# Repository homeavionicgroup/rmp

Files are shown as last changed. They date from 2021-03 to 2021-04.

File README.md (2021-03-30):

# Radio Management Panel for your HomeCockpit
Radio Management Panel for HomeCockpit Use

This Repository shows the requred sources to build a Radio Management Panel for the use with your Home Flightsimulator. Currently it only works with X-Plane (FF320, ToLiss321, FF350) and the MSFS server is currently worked on. 

 # For Flight Simulation use only. No warranties, use at your own risk

Currently the RMP allows following functions:
1. VHF Management 
2. SQWk Management 
3. SIMBrief Integration 
with more to follow.

You need the following: 
1. 3D Model
2. Electronic
3. Some Code

For the full List of parts you need please view the Ingredientslist:
https://github.com/homeavionicgroup/rmp/blob/main/documentation/Ingredients.md

### Screenshots
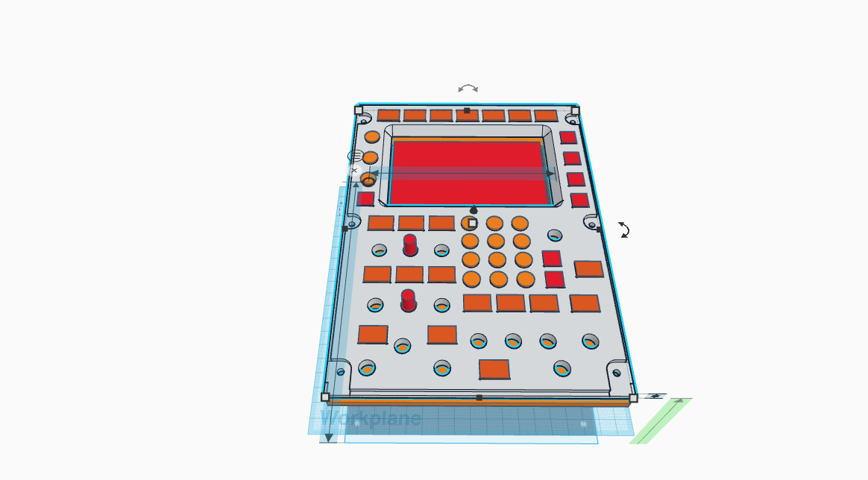
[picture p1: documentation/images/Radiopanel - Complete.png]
ScreenShot Complete


## Wiring
Howto wire all the elements is described in the corresponding documentation: 

# LICENSE
This project and all it's elements are shared under the Creative Commons Attribution-NonCommercial-ShareAlike 4.0 International Public License:
https://creativecommons.org/licenses/by-nc-sa/4.0/

# DISCLAIMER 
 *+For Flight Simulation use only. No warranties, use at your own risk. **

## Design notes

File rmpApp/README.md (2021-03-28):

# Client App

This directory contains the main application and configurations, which runs on the Radio Management Panel. The application is a basic html-app, which can be hosted directly on the PI itself or on an external Webbrowser. 

The client app is configured through the config.js file, which can be found in the /rmpApp/common/js/config.js file. There you store the servers IP-Address + Port and your SimBrief Username, if you want to use the Simbrief feature. The application starts with a simple menu (index_radio.html), which allows you to start the radio configurations for specific planes. Currently only the FF320 is supported with others to come.

# rpi config
The buttons (see wiring) of the Raspberry are directly used as keyboard keys through the dtoverlay option on the raspberry. Put the lines in that configurationsfile in config.txt within the boot directory to load it on boot. 

# Pico Config
As dresribed earlier the raspberry pico is used as GPIO extension and acts as a keyboard connected through USB to the raspberry pi. For this to work load the current circuitpython firmware on your pico and put the code from the Radio-pico.py to the code.py on the pico.

# Key Assignments
Following Key assigments do currently work with the pico:

- LSKL1	    a
- LSKL2	    s
- LSKL3	    d
- LSKL4	    f
- LSKR1	    g
- LSKR2	    h
- LSKR3	    j
- LSKR4	    k
- Menu 1	q
- Menu 2	w
- Menu 3	e
- Menu 4	r
- Menu 5	t
- Menu 6	z
- Menu 7	u
- COM1	    i
- COM2	    o
- COM3	    p
- UP  BTN	UP
- Down BTN	DOWN
- 1 BTN	    1
- 2 BTN	    2
- 3 BTN	    3
- 4 BTN	    4
- 5 BTN	    5
- 6 BTN	    6
- 7 BTN	    7
- 8 BTN	    8
- 9 BTN	    9
- 0 BTN	    0
- . BTN	    .
- CLR BTN	c

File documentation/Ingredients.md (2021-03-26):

# Ingredients 

## 3D Model
The components for the 3D Modell are available as STL to be printed by the 3DPrinter of your choice. The Frontplate is hosted externally but the other (fitting) elements are in the corresponding folder in this repository. 

### Front Plate
As Front Plate I found following available Model on thingyverse: https://www.thingiverse.com/thing:2892991 and adapted it to fit it better with the buttons and the backplate. Checkout russ1364 model portfolio on thingyverse. He has some amazing stuff available if you look for Airbus specific material. 

### Back Plate
To fit the electronics (Buttons, Display etc.)I created a Backplate with holds that stuff and is mouted directly beneath the FrontPlate

### Buttons
You need Buttons in following numbers:
- 21 x Radiopanel-Button-big
- 3 x Radiopanel-Button-round (Big Dot)
- 3 x Radiopanel-Button-small (BAR)
- 2 x Radiopanel-Button-small (up)
- 1 each of (Radiopanel-Button-round (0-9),Radiopanel-Button-round (CLR), Radiopanel-Button-round (Dot), Radiopanel-Button-small (MSGCLR), Radiopanel-Button-small (RST)9

## Electronics

### Elements
You need following eletronics:
- 1 x Raspberry Pi 3 A+ 
- 1 x Waveshare 4.3 inch Touch Display with DSI Interface
- 1 x Raspberry Pico
- 43 x Omron B3F-4030
- 2 x KY-040 Rotary Encoders
- Lots of kables & Soldering equipment
- 1x short Micro USB cable to connect the Pico (20mm)
- 1x Micro USB cable with sufficient length (depending on where your USB Power Source is)
- Some blank PCBs to combine the ground cables (can be solved otherwise)

## Other
To hold everything together I use M4 screws with minimum of 30mm length incl. lots of washers and nuts. As to keep the elecontrics (especially the buttons and rotaries) in place, I use double-sided adhesive pads. For a less chaos I additionally use cable labeles, which makes the wiring a lot easier.

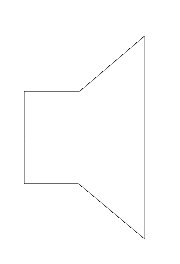
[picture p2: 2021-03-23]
rmpApp/common/img/speakersymbol.png

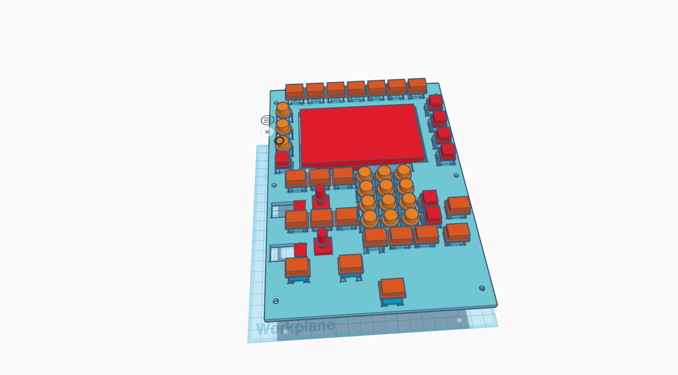
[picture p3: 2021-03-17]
documentation/images/Radiopanel-BackPlate.png

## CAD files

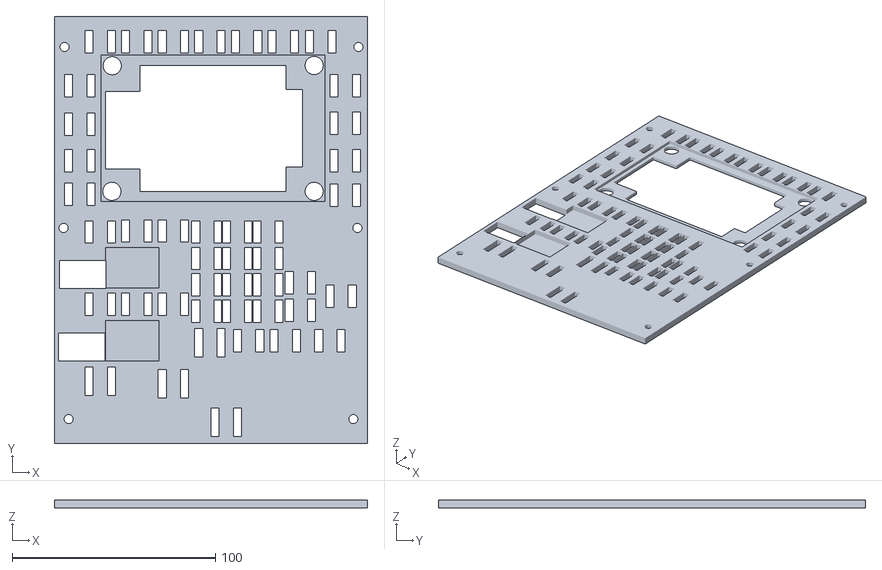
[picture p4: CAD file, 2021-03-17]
3dmodel/Backplate/Radiopanel-BackPlate.stl
154.0 x 210.0 x 4.00

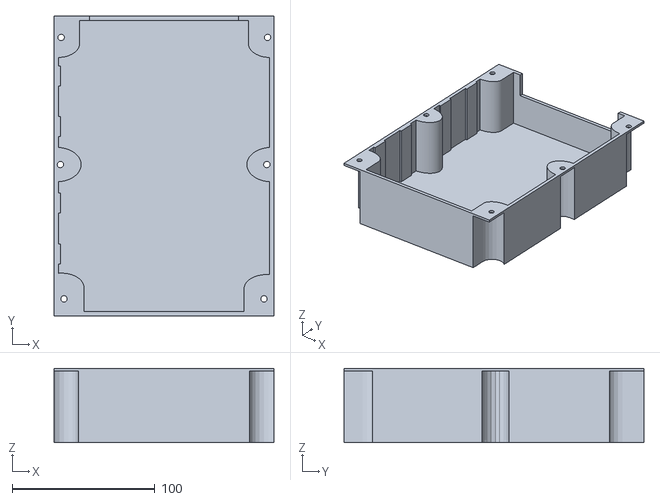
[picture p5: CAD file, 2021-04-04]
3dmodel/Case/Radiopane-case.stl
154.0 x 210.0 x 52.0

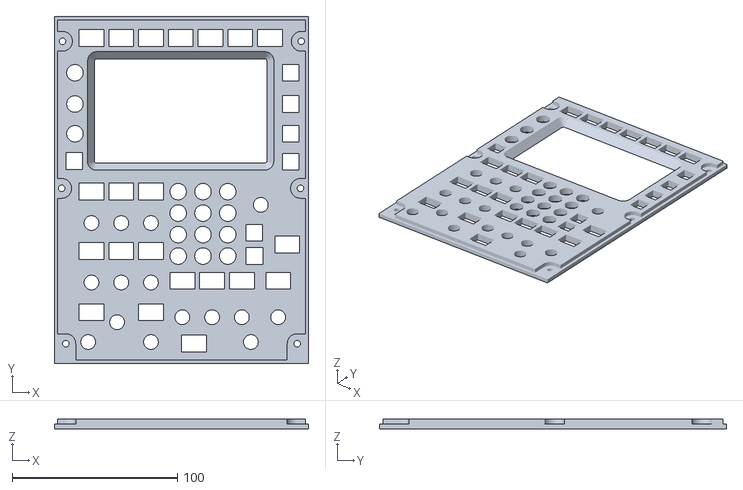
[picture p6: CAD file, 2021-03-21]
3dmodel/FrontPlate/Radiopanel-FrontPlate.stl
154.0 x 210.0 x 6.00

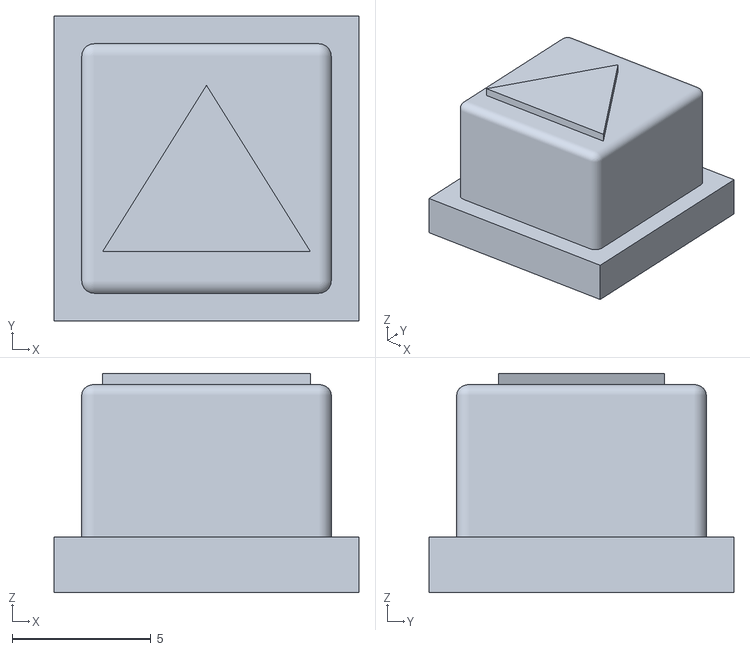
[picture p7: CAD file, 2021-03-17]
3dmodel/Buttons/Radiopanel-Button-small (up).stl
11.0 x 11.0 x 7.90

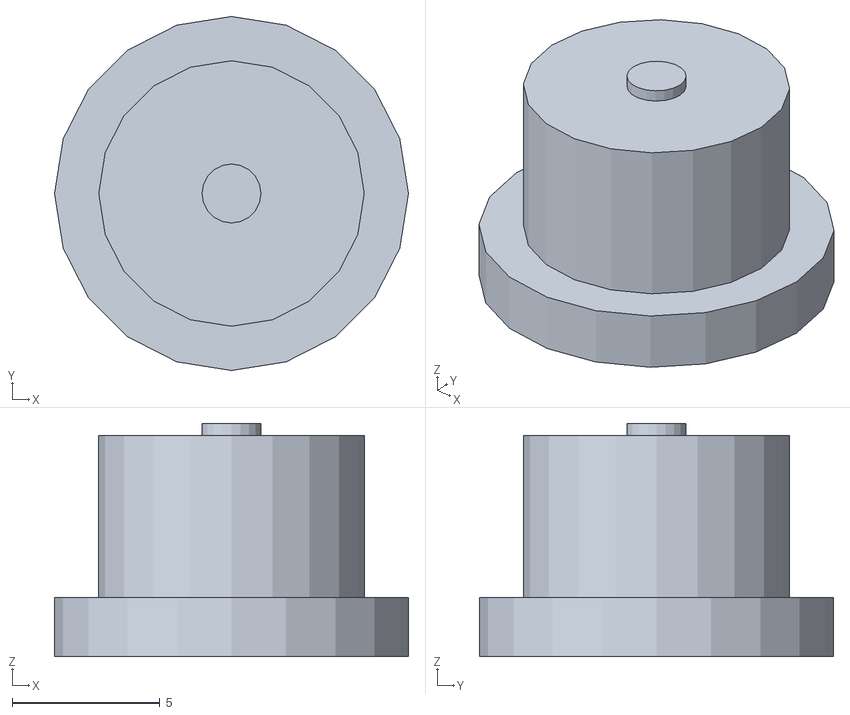
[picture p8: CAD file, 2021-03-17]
3dmodel/Buttons/Radiopanel-Button-round (Dot).stl
12.0 x 12.0 x 7.90

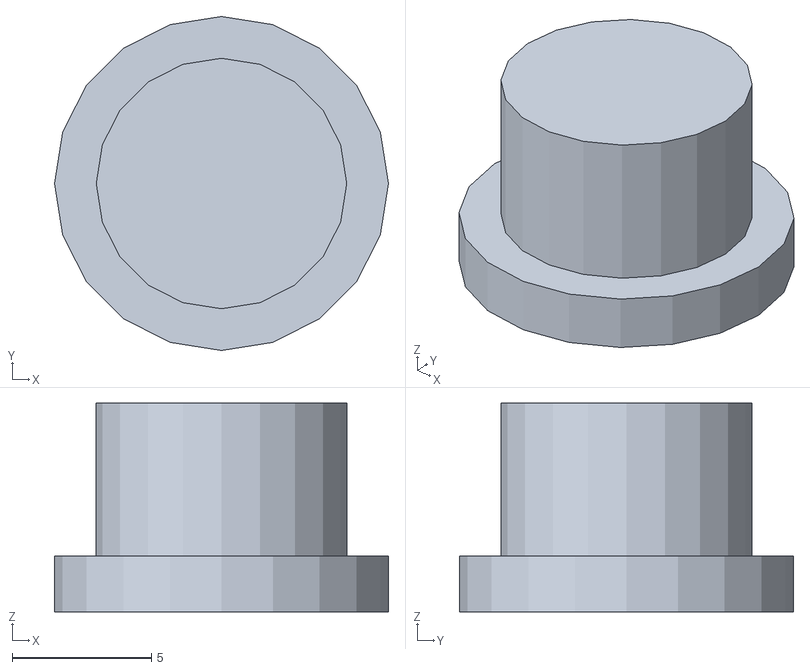
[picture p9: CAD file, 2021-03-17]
3dmodel/Buttons/Radiopanel-Button-round.stl
12.0 x 12.0 x 7.50

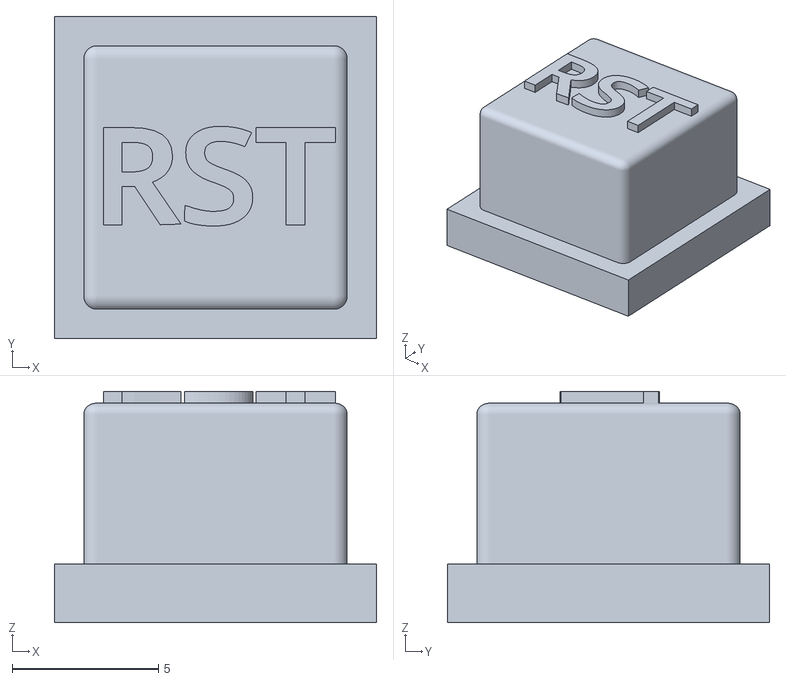
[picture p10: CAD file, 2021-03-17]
3dmodel/Buttons/Radiopanel-Button-small (RST).stl
11.0 x 11.0 x 7.90

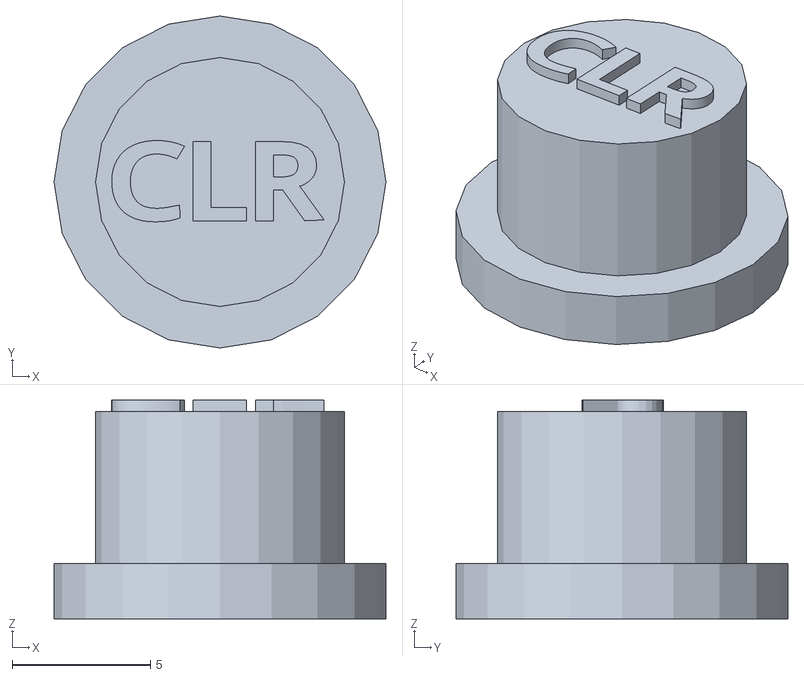
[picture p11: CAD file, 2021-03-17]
3dmodel/Buttons/Radiopanel-Button-round (CLR).stl
12.0 x 12.0 x 7.90

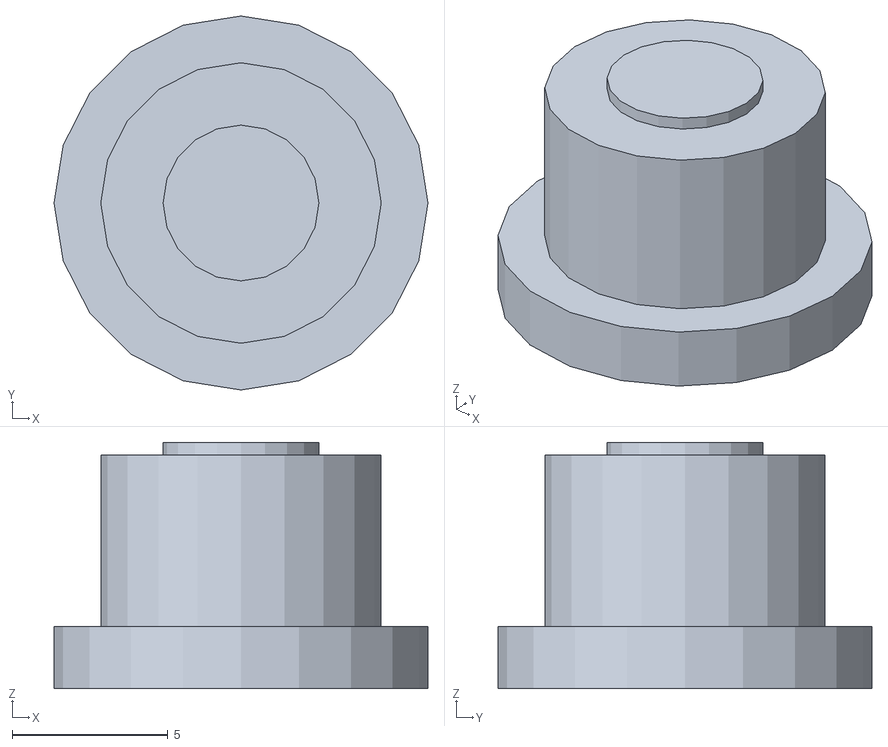
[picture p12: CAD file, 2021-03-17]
3dmodel/Buttons/Radiopanel-Button-round (Big Dot).stl
12.0 x 12.0 x 7.90

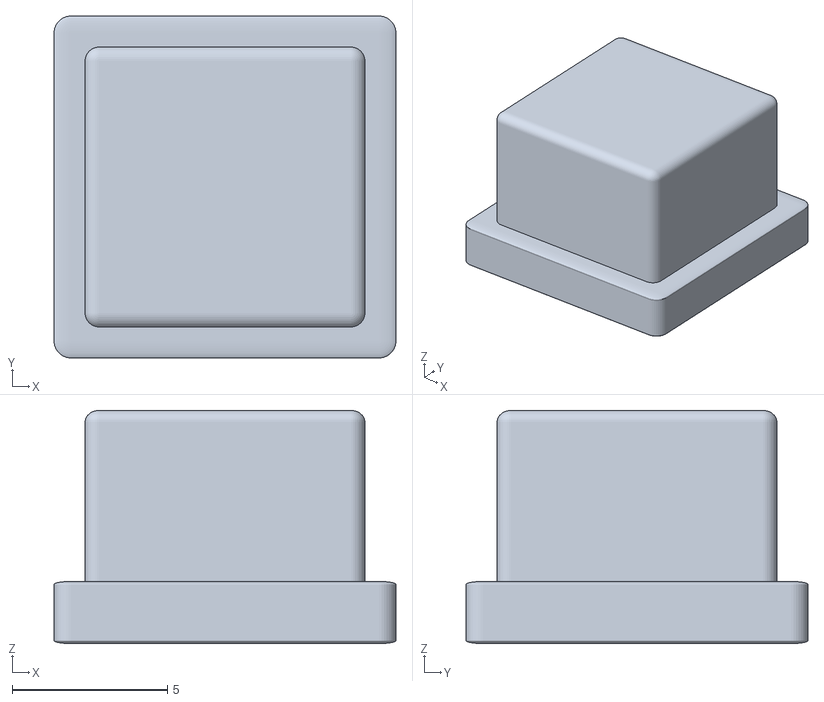
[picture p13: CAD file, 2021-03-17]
3dmodel/Buttons/Radiopanel-Button-small.stl
11.0 x 11.0 x 7.50

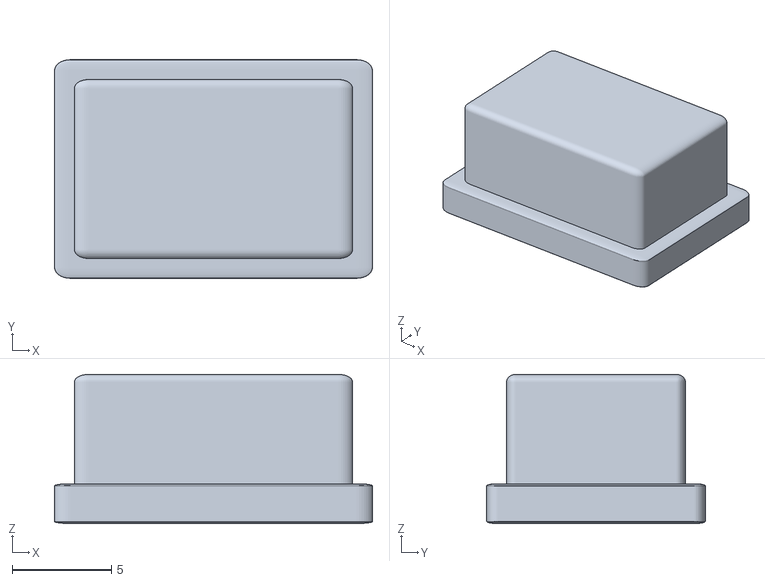
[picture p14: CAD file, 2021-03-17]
3dmodel/Buttons/Radiopanel-Button-big.stl
16.0 x 11.0 x 7.50

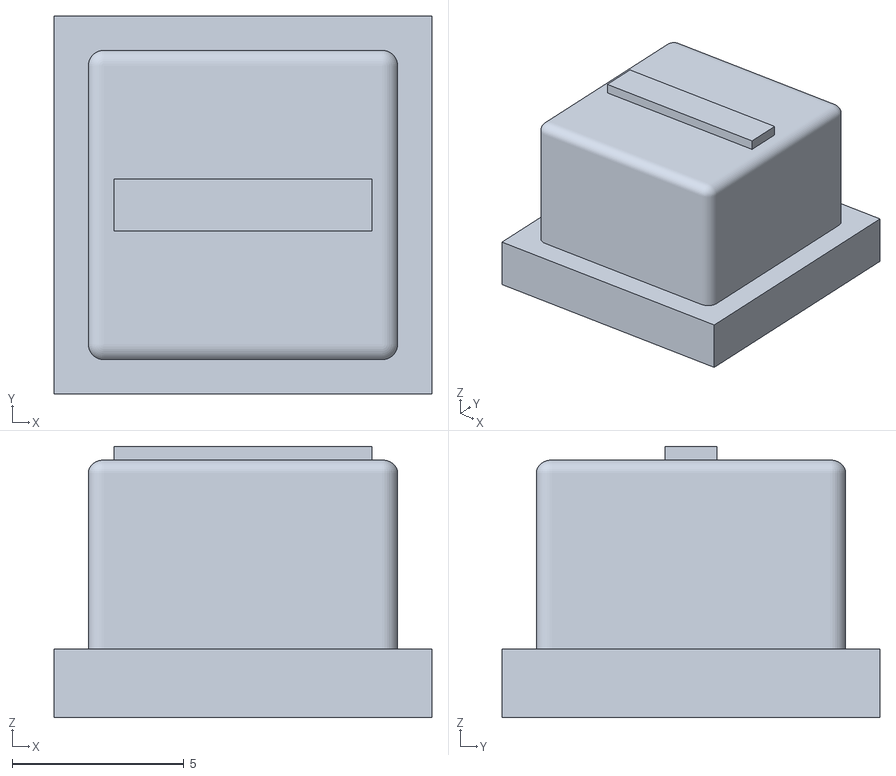
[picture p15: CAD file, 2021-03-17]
3dmodel/Buttons/Radiopanel-Button-small (BAR).stl
11.0 x 11.0 x 7.90

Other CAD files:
3dmodel/Buttons/Radiopanel-Button-small (MSGCLR).stl
3dmodel/Buttons/Radiopanel-Button-round (8).stl
3dmodel/Buttons/Radiopanel-Button-round (5).stl
3dmodel/Buttons/Radiopanel-Button-round (4).stl
3dmodel/Buttons/Radiopanel-Button-round (1).stl
3dmodel/Buttons/Radiopanel-Button-round (0).stl
3dmodel/Buttons/Radiopanel-Button-round (2).stl
3dmodel/Buttons/Radiopanel-Button-round (3).stl
3dmodel/Buttons/Radiopanel-Button-round (6).stl
3dmodel/Buttons/Radiopanel-Button-round (7).stl
3dmodel/Buttons/Radiopanel-Button-round (9).stl

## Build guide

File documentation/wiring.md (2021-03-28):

# Architecture & Wiring

# Wiring
The basic idea and setup is straight forward. The Raspberry Pi is the core of the system. It runs the client web aapplication in a chromium instance. The pico is connected through USB and acts as basic keyboard to provide additonal GPIO. Main reason for that is that the RMP requires more buttons than the RPI kann provide. As i did not had time to build a Button Matrix, I simply chose the Pico as GPIO extension, as it is cheap and available.

The display is connected through DPI, which allows the RPI to be mounted on the back of the display.

The rest of the buttons and other parts are connected to the RPI and Pico as described on the following table. 

Each Button has a keyboard key assigned to. On the RPI the key assignment is done by a dtoverlay configuration, which can be found in the repository. On the pico the keyboard is configured through a circuitpython script. 

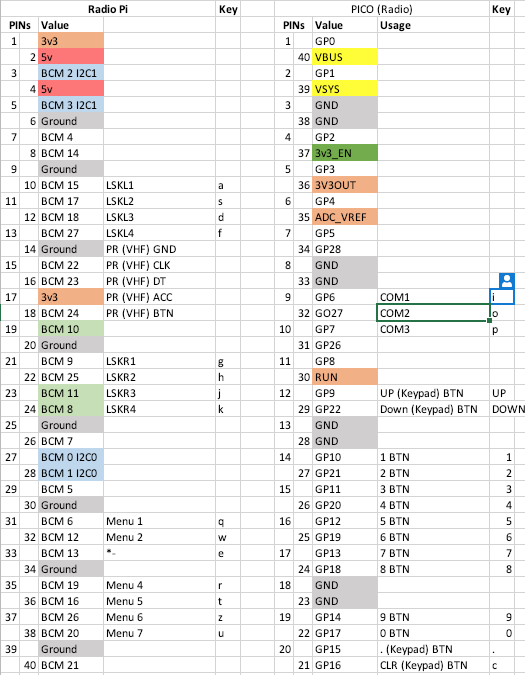
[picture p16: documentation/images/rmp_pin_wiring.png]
Wiring Table


# BuildUp

The buildup is quite simple as the wiring. You start with the backplate and place all the buttons on it and put the cables through the prepared holes. Be careful to use the right side of the backplate, otherwise it will not match the frontplate. I strongly recommend to label each cable, so that you can easiy find the right cable when putting everything on the Pico ans RPI. 

The M4 screws are put from the front, so that backplate and case can be put on the screws. The front plate is fixed by a washer and a nut. A second nut acts as spacer to save room between front-plate and back-plate.

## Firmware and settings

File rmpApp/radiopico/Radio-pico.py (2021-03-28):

import time
import board
import usb_hid
import digitalio
from adafruit_hid.keyboard import Keyboard
from adafruit_hid.keycode import Keycode
from adafruit_hid.keyboard_layout_us import KeyboardLayoutUS

led = digitalio.DigitalInOut(board.LED)
led.direction = digitalio.Direction.OUTPUT
led.value = True

keypress_pins = [board.GP17, board.GP10,board.GP21,board.GP11,board.GP20,board.GP12,board.GP19,board.GP13,board.GP18,board.GP14,board.GP16,board.GP15,board.GP9, board.GP22, board.GP6, board.GP27, board.GP7]

key_pin_array = []

keys_pressed = [Keycode.ZERO, Keycode.ONE, Keycode.TWO, Keycode.THREE, Keycode.FOUR, Keycode.FIVE, Keycode.SIX, Keycode.SEVEN, Keycode.EIGHT, Keycode.NINE, Keycode.PERIOD, Keycode.C, Keycode.UP_ARROW, Keycode.DOWN_ARROW, Keycode.I, Keycode.O, Keycode.P]

time.sleep(5)  # Sleep for a bit to avoid a race condition on some systems
keyboard = Keyboard(usb_hid.devices)
keyboard_layout = KeyboardLayoutUS(keyboard)  # We're in the US :)
led.value = False
for pin in keypress_pins:
    key_pin = digitalio.DigitalInOut(pin)
    key_pin.direction = digitalio.Direction.INPUT
    key_pin.pull = digitalio.Pull.UP
    key_pin_array.append(key_pin)
    
print("Waiting for key pin...")

while True:
    # Check each pin
    for key_pin in key_pin_array:
        if not key_pin.value:  # Is it grounded?
            i = key_pin_array.index(key_pin)
            print("Pin #%d is grounded." % i)

            # Turn on the red LED
            led.value = True

            while not key_pin.value:
                pass  # Wait for it to be ungrounded!
            # "Type" the Keycode or string
            key = keys_pressed[i]  # Get the corresponding Keycode or string
            if isinstance(key, str):  # If it's a string...
                keyboard_layout.write(key)  # ...Print the string
            else:  # If it's not a string...
                keyboard.press(key)  # "Press"...
                keyboard.release_all()  # ..."Release"!

            # Turn off the red LED
            led.value = False

    time.sleep(0.01)



#led.value = False

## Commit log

2021-03-17 Initial Upload 3DModel Backplate + Buttons
    [Radiopanel-BackPlate.stl, Radiopanel-Button-big.stl, Radiopanel-Button-round (0).stl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]
2021-03-21 Added Frontplate
    [Radiopanel-FrontPlate.stl]
2021-03-25 Wiring Description added
2021-03-28 Added main Menufile as landingpage for RMP
2021-03-28 Updated View for WX in SimBrief Mode Added Pico Config File Added dtoverlay config file
2021-04-04 Case for Radio
    [Radiopane-case.stl, Radiopanel-Holder.stl]
2021-04-04 Removed unnecessary files
    [Radiopanel-Holder.stl]
